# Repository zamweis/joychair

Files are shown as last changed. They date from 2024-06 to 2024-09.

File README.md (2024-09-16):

# Joychair - Interface for VR Navigation

Welcome to the Joychair Interface project! This project integrates the movements of an [Aeris Swopper chair](https://en.aeris.de/products/aeris-swopper-wollmischung-capture-gruen) into virtual reality (VR) environments, allowing users to navigate virtual worlds by shifting their weight on the chair. The idea is inspired by the concept of ChairIO, as described in the paper ["ChairIO - the Chair-Based Interface"](https://www.researchgate.net/publication/233819716_ChairIO--the_Chair-Based_Interface).

## Project Overview

The Joychair Interface project is developed at the iXperience Lab of the Faculty of Computer Science and Business Information Systems. The goal is to capture the movements of the Aeris Swopper chair and integrate them into a solution that can be used within VR environments, particularly in Unity.

The project was developed using the PlatformIO plugin for VSCode. The libraries used are also available for ArduinoIDE. The recommended version for wireless support is the ESP32 version; for wired, use the Arduino one.

## Project Components

### Hardware Parts
- M2.5 Machine Screws and Nuts
- 2000mAh Battery
- SPDT Slide Switch
- JST-PH (Male)
- JST-PH (Female)
- JST-PH extension cable (optional but helpful)
- Buzzer (active or passive)
- RGB LED (optional LED)
- MPU6050 (Inertial Measurement Unit)
- Compatible microcontroller (e.g., ESP32, Arduino)

### Hardware Setup

The project uses microcontroller boards with an IMU sensor attached to the chair. The IMU captures the chair's movements, which are then transmitted wirelessly or via wired connections.

- [Arduino Leonardo Setup](./arduino_leonardo)
- [ESP32 Setup](./esp32)
- [Feather 32u4 Bluefruit LE Setup](./feather32u4_bluefruit_le)

### Unity Integration

In Unity, the output is used to control the user's movement within the VR environment. By shifting their weight on the chair, users can navigate virtual worlds seamlessly.

## Setup Instructions

To set up the Joychair Interface project, follow these steps:

1. **Hardware Setup**: Attach the IMU sensor to the Aeris Swopper chair as per the instructions provided.
2. **Microcontroller Configuration**: Program the microcontroller board to read data from the IMU and transmit it wirelessly or via a wired connection.
3. **Unity Integration**: Import the output into Unity and configure the VR environment to respond to the chair's movements for navigation.
4. **Optional Casing**: For battery integration, follow a rechargeable battery tutorial. CAD for ESP32 is in progress.

## Features and Functionalities

The Joychair Interface provides several key functionalities:

### Initialization

- **MPU6050 Setup**: Initializes the MPU6050 IMU and ensures connectivity. Plays an initialization sound to confirm startup.

### Connection Management

- **Continuous Monitoring**: Checks the connection to the MPU6050 sensor and attempts to reconnect if the connection is lost, ensuring stable operation.

### Data Processing

- **Sensor Data Acquisition**: Reads data from the IMU, including yaw, pitch, and roll.
- **Axis Mapping**: Maps the processed sensor data to joystick axes (X, Y, Z, RX, RY, RZ) for VR navigation.

### Calibration and Direction Declaration

- **Sitting Detection**: Waits for the user to sit by monitoring acceleration in the Z-axis to exceed a threshold.
- **Forward Tilt Calibration**: Prompts the user to tilt forward to calibrate the forward direction. Plays a success sound upon completion.

### Joystick Output

- **Real-time Axis Mapping**: Continuously updates joystick inputs based on chair movement.
- **Deadzone Application**: Applies deadzones to joystick inputs to filter out noise and minor movements.

### Visual and Auditory Feedback

- **LED Indicators**: Uses RGB LED to provide visual status indicators, including connection status and error notifications.
- **Buzzer Sounds**: Emits sounds for different events such as initialization, errors, success, and setup completion.

### Battery Level Monitoring

- **Analog Reading**: Reads the battery level via Sparkfun Fuel Gauge

### Additional Functionalities

- **Jump Detection**: Detects rapid acceleration changes to emulate a "jump" button press.
- **Recalibration Button**: Allows recalibration of the forward direction by pressing a designated button on the microcontroller.
- **Reset Button**: Allows to reset the microcontroller.

## Axis Mapping and Joystick Calibration

When integrating the Joychair with a VR environment, it is essential to adjust the axis mappings to suit the target application's requirements. The joystick values, derived from the MPU6050 sensor readings, must be mapped within the appropriate intervals for your setup.

### Adjusting Axis Mapping

The mapping of the pitch, roll, and yaw values to joystick inputs is critical for achieving smooth and intuitive navigation. Depending on the VR application's sensitivity and control scheme, you may need to calibrate the mapping intervals.

1. **Define the Mapping Range:**
   - Determine the minimum and maximum tilt angles corresponding to the joystick's minimum and maximum values. This range should reflect the comfortable and natural tilting limits of the Aeris Swopper chair.

2. **Adjust the Intervals:**
   - Modify the code to map the sensor readings to the joystick values. Ensure the mapping intervals match the expected input range of your VR application. For instance, if your application expects joystick values from 0 to 32767, you need to map the sensor's tilt range to this interval.

3. **Minimum Tilt Threshold:**
   - Set a minimum tilt threshold to ensure that only intentional movements result in joystick input. This threshold helps filter out minor, unintentional shifts and maintains a stable VR navigation experience.

### Example Code Snippet for Axis Mapping

```cpp
// Define the minimum and maximum tilt angles (in degrees)
const float minTiltAngle = -10.0;
const float maxTiltAngle = 10.0;

// Define the joystick input range
const int joystickMinValue = 0;
const int joystickMaxValue = 32767;

// Function to map tilt to joystick value
int mapTiltToJoystick(float tiltAngle) {
    return map(tiltAngle, minTiltAngle, maxTiltAngle, joystickMinValue, joystickMaxValue);
}

// Example usage in the main loop
void loop() {
    // Get the tilt angles from the MPU6050
    float pitch = ...; // Get the pitch angle
    float roll = ...;  // Get the roll angle

    // Map the tilt angles to joystick values
    int joystickX = mapTiltToJoystick(pitch);
    int joystickY = mapTiltToJoystick(roll);

    // Apply the mapped values to the joystick
    bleGamepad.setAxes(joystickX, joystickY, ...);
}
```
## Additional Info ##

### Battery Level

LED Blink Red: Battery below 20%  
LED Blink Yellow: Battery over 20%   
LED Blink Green: Battery over 50%  

### Example

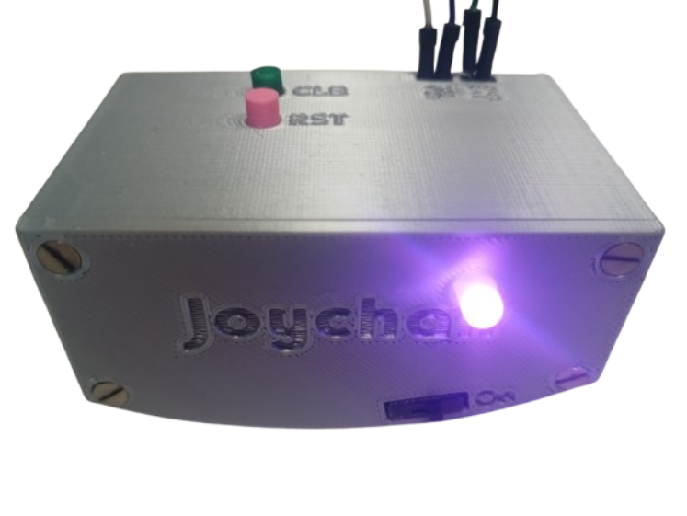
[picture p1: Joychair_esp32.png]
Joychair - ESP32


## Additional Resources

- [Aeris Swopper Product Page](https://en.aeris.de/products/aeris-swopper-wollmischung-capture-gruen): Learn more about the Aeris Swopper chair.
- [Arduino Joystick Tutorial](https://www.instructables.com/Create-a-Joystick-Using-the-Arduino-Joystick-Libra/): Useful guide for setting up the Arduino Leonardo as a joystick.
- [MPU6050 Wiring Guide](https://images.app.goo.gl/LdwjNLMtsEHgnhpH7): How to wire MPU6050
- [Buzzer Wiring Guide](https://images.app.goo.gl/mgFJdeP5EhSxzM8t5): How to wire a buzzer
- [RGB-LED Wiring Guide](https://images.app.goo.gl/b1UZzW2y5GSzTEi26): How to wire an RGB-LED
- [Rechargeable Battery Integration](https://learn.adafruit.com/3d-printed-case-for-adafruit-feather/assembly): How to wire a rechargeable battery  

## Contributors

- Sam Weiler (@zamweis)

## License

This project is licensed under the MIT License. See the [LICENSE](LICENSE) file for details.

---

Feel free to reach out to the project team for any questions or feedback. Happy navigating in VR with Joychair Interface! 🎮🪑🌐

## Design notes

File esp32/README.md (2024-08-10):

# Joychair Interface for VR Navigation - ESP32

Welcome to the Joychair Interface project for ESP32! This setup enables you to integrate the dynamic movements of an Aeris Swopper chair into virtual reality (VR) environments using a SparkFun ESP32 Thing board. The ESP32 communicates data wirelessly via Bluetooth, providing seamless interaction within VR applications.

## Project Overview

The Joychair Interface captures and translates the movements of the Aeris Swopper chair into VR environments, particularly in Unity. The setup uses an ESP32 microcontroller to read data from an Inertial Measurement Unit (IMU) and transmit it wirelessly. Additionally, the system includes a battery management solution, featuring a power switch and a fuel gauge for real-time battery monitoring.

## Hardware Setup

### Components
- **ESP32 (SparkFun ESP32 Thing)**
- **MPU6050 IMU (Inertial Measurement Unit)**
- **Buzzer**
- **RGB LED**
- **Battery with Power Switch**
- **MAX1704x Fuel Gauge**
- **Aeris Swopper Chair**

### Wiring
1. **MPU6050 IMU to ESP32:**
   - Connect via I2C (SDA to GPIO4, SCL to GPIO17).
   - Attach the IMU securely to the Aeris Swopper chair.
2. **Buzzer to ESP32:**
   - Connect the buzzer to a GPIO pin (e.g., GPIO6).
3. **RGB LED to ESP32:**
   - Connect the RGB LED to three GPIO pins (e.g., GPIO11 for red, GPIO10 for green, GPIO9 for blue).
4. **Battery Setup:**
   - Connect the battery to the power switch, and then connect the power switch to the MAX1704x fuel gauge.
   - Connect the fuel gauge to the ESP32 to monitor the battery level.
5. **Power and Ground Connections:**
   - Ensure all components share a common ground and are powered appropriately by the battery.

### Casing
The components should be housed securely to protect them from damage during use. You can 3D print the casing using the provided STL files.

### Spatial Light Transfer Files
You can find the STL files for the casing in the [case](./case) directory:
- [Case.stl](./case/case.STL)
- [Case_Lid.stl](./case/case_lid.STL)
- [Push_Button.stl](./case/push_button.STL)

## Software Setup

### Libraries
Ensure the following libraries are installed in your PlatformIO project:

```ini
lib_deps = 
    lemmingdev/ESP32-BLE-Gamepad@^0.5.5
    mbed-syundo0730/I2Cdev@0.0.0+sha.3aa973ebe3e5
    electroniccats/MPU6050@^1.3.1
    https://github.com/sparkfun/SparkFun_MAX1704x_Fuel_Gauge_Arduino_Library.git
```

## Functionality

### Battery Management
The setup includes a MAX1704x fuel gauge that monitors the battery level, providing real-time updates to the ESP32. This ensures the system can alert the user if the battery is running low, and manage power efficiently.

### LED Indicators
The RGB LED provides visual feedback on the system’s status:
- **Red Blinking:** An error has occurred.
- **Green Blinking:** Initialization is in progress.
- **Blue Blinking:** Bluetooth device is not connected.
- **Green Static:** Initialization completed successfully.
- **Pink Static:** System is operating normally.
- **Red/Yellow/Green (Static/Blinking):** Indicates battery level, where red indicates low battery, yellow indicates medium, and green indicates high.

### Code Overview
The provided code turns the ESP32 into a Bluetooth LE gamepad, which reads IMU data and transmits it over Bluetooth. It also manages power based on battery levels and provides visual and auditory feedback via the LED and buzzer.

## Usage Instructions
1. **Setup the hardware** according to the wiring instructions.
2. **Flash the code** to the ESP32 using PlatformIO.
3. **Power on the system** using the power switch connected to the battery.
4. **Monitor the LED indicators** to ensure everything is functioning correctly.
5. **Use the Joychair** to navigate in your VR environment, with movements of the Aeris Swopper chair translated directly into VR motion.

## Troubleshooting
- If the LED blinks red, check the connections and ensure all components are properly wired and powered.
- If the battery level is low, charge or replace the battery to ensure continuous operation.
- If the MPU6050 fails to initialize, verify the I2C connections and ensure the IMU is correctly attached to the ESP32.

## Conclusion
The Joychair Interface brings a new dimension to VR navigation, making interactions more immersive and intuitive. With proper setup and usage, this system can greatly enhance your VR experiences.

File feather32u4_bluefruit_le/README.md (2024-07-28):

# Joychair Interface for VR Navigation - Feather 32u4 Bluefruit LE

Welcome to the Joychair Interface project for Feather 32u4 Bluefruit LE! This setup allows you to integrate the movements of an Aeris Swopper chair into virtual reality (VR) environments using a Feather 32u4 Bluefruit LE board. Note: Currently, only wired transmission is supported as the Bluetooth function is not working properly.

## Project Overview

The Joychair Interface captures the movements of the Aeris Swopper chair and integrates them directly into VR environments, particularly in Unity. This setup uses the Feather 32u4 Bluefruit LE microcontroller to read data from an Inertial Measurement Unit (IMU) and transmit it via a wired connection.

## Hardware Setup

### Components
- **Feather 32u4 Bluefruit LE**
- **MPU6050 IMU**
- **Buzzer**
- **RGB LED**
- **Aeris Swopper Chair**

### Casing
3D-printed with Prusa MK2  
[Thingiverse](https://www.thingiverse.com/thing:2209964) file  
[Additional Tutorial](https://learn.adafruit.com/3d-printed-case-for-adafruit-feather/overview) for accu/battery integration  

### Wiring
1. Connect the MPU6050 IMU to the Feather 32u4 via I2C (SDA to SDA, SCL to SCL).
2. Connect the buzzer to a GPIO pin (e.g., GPIO6).
3. Connect the RGB LED to three GPIO pins (e.g., GPIO11 for red, GPIO10 for green, GPIO9 for blue).
4. Attach the MPU6050 IMU to the Aeris Swopper chair.

## Software Setup

### Libraries
Make sure you have the following libraries installed in your PlatformIO project:

```ini
lib_deps = 
    mbed-syundo0730/I2Cdev@0.0.0+sha.3aa973ebe3e5
    electroniccats/MPU6050@^1.3.1
    adafruit/Adafruit BluefruitLE nRF51@^1.0.0

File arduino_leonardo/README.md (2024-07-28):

# Joychair Interface for VR Navigation - Arduino Leonardo

Welcome to the Joychair Interface project for Arduino Leonardo! This setup allows you to integrate the movements of an Aeris Swopper chair into virtual reality (VR) environments using an Arduino Leonardo board and sensors.

## Project Overview

The Joychair Interface captures the movements of the Aeris Swopper chair and integrates them into a solution for VR environments, particularly in Unity. This setup uses the Arduino Leonardo microcontroller to read data from an Inertial Measurement Unit (IMU) and transmit it wirelessly/wired.

## Hardware Setup

### Components
- **Arduino Leonardo**
- **MPU6050 IMU**
- **Buzzer**
- **Aeris Swopper Chair**

### Casing
3D-printed with a prusa MK2  
[Thingiverse](https://www.thingiverse.com/thing:628929) file  

### Wiring
1. Connect the MPU6050 IMU to the Arduino Leonardo via I2C (SDA to A4, SCL to A5).
2. Connect the buzzer to pin 6 of the Arduino Leonardo.
3. Attach the MPU6050 IMU to the Aeris Swopper chair.

## Software Setup

### Libraries
Make sure you have the following libraries installed in your PlatformIO project:

```ini
lib_deps = 
    mheironimus/Joystick@^2.1.1
    mike-matera/ArduinoSTL@^1.3.3
    mbed-syundo0730/I2Cdev@0.0.0+sha.3aa973ebe3e5
    electroniccats/MPU6050@^1.3.1

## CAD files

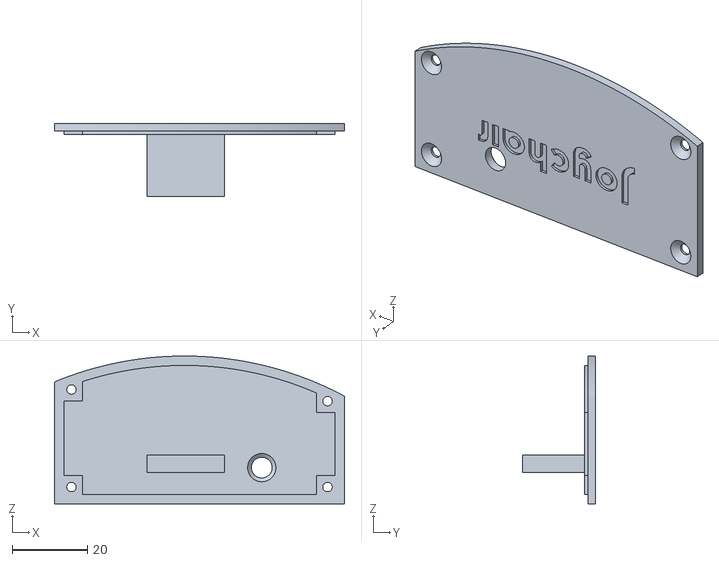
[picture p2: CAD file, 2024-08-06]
esp32/case/case_lid.STL
77.0 x 19.5 x 39.3

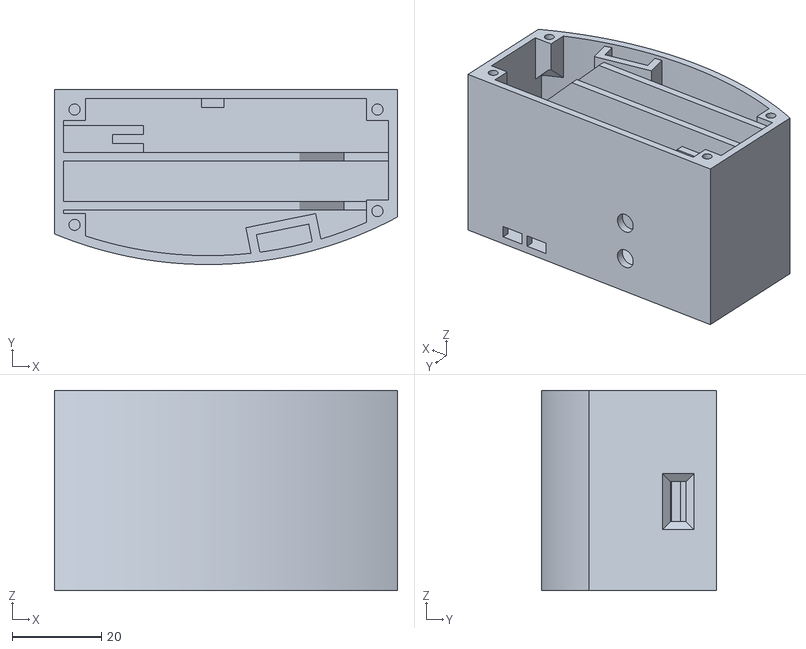
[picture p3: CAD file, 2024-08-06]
esp32/case/case.STL
77.0 x 39.3 x 45.0

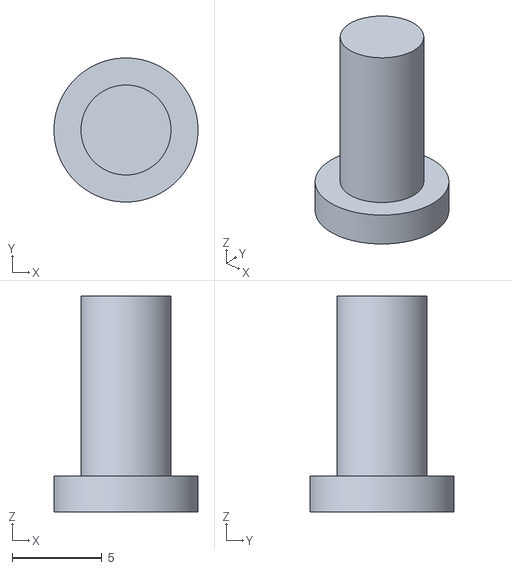
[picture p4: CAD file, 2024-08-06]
esp32/case/push_button.STL
8.00 x 8.00 x 12.0

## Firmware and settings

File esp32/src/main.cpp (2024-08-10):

/*
 * This example turns the ESP32 into a Bluetooth LE gamepad that presses buttons and moves axis
 *
 * At the moment we are using the default settings, but they can be canged using a BleGamepadConfig instance as parameter for the begin function.
 *
 * Possible buttons are:
 * BUTTON_1 through to BUTTON_16
 * (16 buttons by default. Library can be configured to use up to 128)
 *
 * Possible DPAD/HAT switch position values are:
 * DPAD_CENTERED, DPAD_UP, DPAD_UP_RIGHT, DPAD_RIGHT, DPAD_DOWN_RIGHT, DPAD_DOWN, DPAD_DOWN_LEFT, DPAD_LEFT, DPAD_UP_LEFT
 * (or HAT_CENTERED, HAT_UP etc)
 *
 * bleGamepad.setAxes sets all axes at once. There are a few:
 * (x axis, y axis, z axis, rx axis, ry axis, rz axis, slider 1, slider 2)
 *
 * Library can also be configured to support up to 5 simulation controls
 * (rudder, throttle, accelerator, brake, steering), but they are not enabled by default.
 *
 * Library can also be configured to support different function buttons
 * (start, select, menu, home, back, volume increase, volume decrease, volume mute)
 * start and select are enabled by default
 */

#include <BleGamepad.h>
#include <Wire.h>
#include "I2Cdev.h"
#include "MPU6050_6Axis_MotionApps20.h"
#include <SparkFun_MAX1704x_Fuel_Gauge_Arduino_Library.h>

// Define the number of buttons and hat switches
#define numOfButtons 1 // No physical buttons, no virtual buttons needed
#define numOfHatSwitches 0 // No hat switches

// Enable axes based on MPU6050 capabilities
#define enableX true
#define enableY true
#define enableZ true
#define enableRZ true
#define enableRX true
#define enableRY true
#define enableSlider1 false
#define enableSlider2 false
#define enableRudder false
#define enableThrottle false
#define enableAccelerator false
#define enableBrake false
#define enableSteering false

// Function and variable declarations
void blinkLED();
void recalibrate();
void playInitSound();
int getBatteryLevel();
void playErrorSound();
void playSuccessSound();
bool initializeMPU6050();
void printJoystickValues();
void playSetupCompleteSound();
void printRollPitchYawAccelZ();
void setLEDColor(String color);
int applyDeadzone(int value, int deadzone);
float calculateTilt(float pitch, float roll);
float calculateRelativeAngle(float accelX, float accelY, float accelZ);

// Define pin numbers for the RGB LED and button
int redPin = 26;
int greenPin = 25;
int bluePin = 27;
int buzzerPin = 13;
int bootButtonPin = 0;  // Boot button is typically connected to GPIO 0
long lastBlink = 0;  // will store last time LED was updated
long blinkInterval = 500;  // interval at which to blink (milliseconds)
bool isConnected = false;
bool blinkRed = false;
bool blinkGreen = false;
bool blinkYellow = false;


// Battery
int batteryPin = 36; // ADC1 channel 0 is GPIO36
float minBatteryVoltage = 3.0; // Minimum expected battery voltage (discharged LiPo)
float maxBatteryVoltage = 4.2; // Maximum expected battery voltage (fully charged LiPo)

uint16_t packetSize;
uint8_t fifoBuffer[64];

Quaternion q;
VectorFloat gravity;
float ypr[3];  // yaw, pitch, roll
float yaw;
float pitch;
float roll;
float accelX;
float accelY;
float accelZ;
float relativeAngle; // Angle of sensor rotation
float maxTiltAngle; // Maximal tilt angle of player

MPU6050 mpu;

SFE_MAX1704X lipo; // Defaults to the MAX17043

BleGamepad bleGamepad("Joychair", "iXperienceLab", 50);

int joystickX;
int joystickY;
int joystickZ;
int joystickRx;
int joystickRy;
int joystickRz;

float cosAngle;
float sinAngle; 

int jumpThreshold = 3000;

bool forwardDirectionDefined = false;
bool sittingCheckComplete = false;
bool mpuInitialized = false;
unsigned long lastTiltCheckTime = 0;
unsigned long lastJumpTime = 0; // Track the last jump time
const unsigned long jumpCooldown = 500; // 500ms cooldown between jumps
const unsigned long calibrationDuration = 5000; // Calibration duration in milliseconds
const float tiltMinimum = 5; // Tolerance for tilt check in radiants
const float sittingAccelZThreshold = 4000; // Threshold for detecting sitting
const float maxTiltTolerance = 45; // maximal estimated possible tilt 

void setup() {
  Serial.begin(115200);
  Wire.begin(4, 17);  
  playInitSound();

  digitalWrite(redPin, HIGH);
  digitalWrite(greenPin, LOW);
  digitalWrite(bluePin, HIGH);

  if (lipo.begin() == false) {
    Serial.println(F("MAX17043 not detected. Please check wiring. Freezing."));
    while (1)
      ;
  }
  
  lipo.quickStart();

  // initialize the digital pin as an output.
  pinMode(redPin, OUTPUT);
  pinMode(greenPin, OUTPUT);
  pinMode(bluePin, OUTPUT);

  // Initialize the battery pin as an input
  pinMode(batteryPin, INPUT);

  // Initialize the boot button pin as input with internal pull-up resistor
  pinMode(bootButtonPin, INPUT_PULLUP);

  Serial.println("Starting BLE work!");
  // Initialize BLE Gamepad
  BleGamepadConfiguration bleGamepadConfig;
  bleGamepadConfig.setControllerType(CONTROLLER_TYPE_GAMEPAD);
  bleGamepadConfig.setButtonCount(numOfButtons);
  bleGamepadConfig.setHatSwitchCount(numOfHatSwitches);
  bleGamepadConfig.setWhichAxes(enableX, enableY, enableZ, enableRX, enableRY, enableRZ, enableSlider1, enableSlider2);
  bleGamepadConfig.setWhichSimulationControls(enableRudder, enableThrottle, enableAccelerator, enableBrake, enableSteering);
  bleGamepadConfig.setModelNumber("1.0");
  bleGamepadConfig.setSoftwareRevision("Software Rev 1");
  bleGamepadConfig.setSerialNumber("1337");
  bleGamepadConfig.setFirmwareRevision("2.0");
  bleGamepadConfig.setHardwareRevision("4.0");

  bleGamepad.begin(&bleGamepadConfig);
  if (!initializeMPU6050()) {
    Serial.println("Failed to initialize MPU6050. Check connections and restart.");
    while (true) {
      delay(500);
      playErrorSound();
      delay(500);
    }
  }

  Serial.println("Waiting for player to sit down...");
  playInitSound();
}

void loop() {
  long currentMillis = millis();
  float soc = lipo.getSOC();
  // Set LED color based on battery level
  if (soc < 20.0) {
    setLEDColor("red");
  } else if (soc < 50.0) {
    setLEDColor("yellow");
  } else {
    setLEDColor("green");
  }  

  static unsigned long lastButtonPressTime = 0; 
  static bool lastButtonState = HIGH; 
  bool currentButtonState = digitalRead(bootButtonPin); 

  if (currentButtonState == LOW && lastButtonState == HIGH && currentMillis - lastButtonPressTime >= 1000) {
    recalibrate();  
    lastButtonPressTime = currentMillis; 
  }
  lastButtonState = currentButtonState; 

  if (!mpu.testConnection()) {
    Serial.println("MPU6050 connection lost. Trying to reconnect...");
    playErrorSound();
    unsigned long startAttemptTime = millis();
    while (!mpu.testConnection() && millis() - startAttemptTime < 10000) { 
      delay(500);
      Serial.print(".");
      if (!mpuInitialized) {
        initializeMPU6050();
      }
    }

    if (mpu.testConnection()) {
      Serial.println("MPU6050 reconnected.");
      playSuccessSound();
    } else {
      Serial.println("Failed to reconnect MPU6050.");
      playErrorSound();
      blinkLED();
      delay(5000); 
      return;
    }
  }

  if (mpu.dmpGetCurrentFIFOPacket(fifoBuffer)) {
    mpu.dmpGetQuaternion(&q, fifoBuffer);
    mpu.dmpGetGravity(&gravity, &q);
    mpu.dmpGetYawPitchRoll(ypr, &q, &gravity);

    accelZ = mpu.getAccelerationZ() - 16383;
    yaw = ypr[0] * 180 / M_PI;
    pitch = ypr[1] * 180 / M_PI;
    roll = ypr[2] * 180 / M_PI;

    if (!sittingCheckComplete) {
      if (accelZ > sittingAccelZThreshold) {
        playSuccessSound();
        sittingCheckComplete = true;
        Serial.println("Player detected.");
        Serial.println("Tilt forward and hold for a few seconds...");
        setLEDColor("green");
      }
      blinkLED();
      return;
    }

    if (!forwardDirectionDefined) {
      if (calculateTilt(pitch, roll) >= tiltMinimum) {
        if (lastTiltCheckTime == 0) {
          lastTiltCheckTime = millis(); 
          playInitSound();
        } else if (currentMillis - lastTiltCheckTime >= calibrationDuration) {
          relativeAngle = -calculateRelativeAngle(mpu.getAccelerationX(), mpu.getAccelerationY(), mpu.getAccelerationZ());
          Serial.print("Relative Angle: ");
          Serial.println(relativeAngle);

          forwardDirectionDefined = true;
          playSetupCompleteSound();
          Serial.println("Forward direction defined!");
          Serial.println("Setup Complete!");
        }
        if (maxTiltAngle < calculateTilt(pitch, roll) && calculateTilt(pitch, roll) <= maxTiltTolerance) {
          maxTiltAngle = calculateTilt(pitch, roll);
        }
      } else {
        if (lastTiltCheckTime != 0) { 
          playErrorSound();
        }
        lastTiltCheckTime = 0; 
      }
      blinkLED();
      return;
    }

    if (maxTiltAngle < calculateTilt(pitch, roll) && calculateTilt(pitch, roll) <= maxTiltTolerance) {
      maxTiltAngle = calculateTilt(pitch, roll);
    } 

    float cosAngle = -cos(relativeAngle);
    float sinAngle = -sin(relativeAngle);

    float newRoll = pitch * sinAngle + roll * cosAngle;
    float newPitch = pitch * cosAngle - roll * sinAngle;

    newRoll = constrain(newRoll, -maxTiltAngle, maxTiltAngle);
    newPitch = constrain(newPitch, -maxTiltAngle, maxTiltAngle);

    joystickX = map(newRoll, -maxTiltAngle, maxTiltAngle+1, 0, 32767);
    joystickY = map(newPitch, -maxTiltAngle, maxTiltAngle+1, 0, 32767);
    joystickZ = map(accelZ, -32767, 32767, 0, 32767);
    joystickRx = map(newRoll, -90, 90, 0, 32767);
    joystickRy = map(newPitch, -90, 90, 0, 32767);
    joystickRz = map(yaw, -180, 180, 0, 32767); 

    joystickX = applyDeadzone(joystickX, 5);
    joystickY = applyDeadzone(joystickY, 5);

    if (bleGamepad.isConnected()) {
      if (accelZ > jumpThreshold) {
        Serial.println("Jump detected!");
        bleGamepad.press(BUTTON_1);
      } else {
        bleGamepad.release(BUTTON_1);
      }
      bleGamepad.setAxes(joystickX, joystickY, joystickZ, joystickRz, joystickRx, joystickRy);
      bleGamepad.setBatteryLevel(soc);
      isConnected=true;
    } else {
      isConnected = false;
    }
  }
  blinkLED();
}

bool initializeMPU6050() {
  Serial.println("Initializing...");

  // Initialize MPU6050
  mpu.initialize();
  if (!mpu.testConnection()) {
    Serial.println("MPU6050 connection failed!");
    playErrorSound();
    mpuInitialized = false;
    return false;
  }

  // Initialize DMP
  uint8_t devStatus = mpu.dmpInitialize();
  if (devStatus == 0) {
    mpu.setDMPEnabled(true);
    packetSize = mpu.dmpGetFIFOPacketSize();
    Serial.println("DMP ready!");
    mpuInitialized = true;
  } else {
    Serial.print("DMP Initialization failed (code ");
    playErrorSound();
    Serial.print(devStatus);
    Serial.println(")");
    mpuInitialized = false;
    return false;
  }

  mpu.CalibrateAccel();
  mpu.CalibrateGyro();
  Serial.println("Calibration complete!");
  playSuccessSound();
  return true;
}

int applyDeadzone(int value, int deadzone) {
  // Calculate center of output range
  const int center = 511; // Center for range [0, 1023]
  int distance = value - center;

  // If the distance from the center is less than the deadzone, set output to center
  if (abs(distance) < deadzone) {
    return center;
  } else {
    // If outside the deadzone, adjust value linearly from the edge of the deadzone
    return (distance > 0) ? map(distance, deadzone, 511, center + deadzone, 1023) :
                            map(distance, -511, -deadzone, 0, center - deadzone);
  }
}

float calculateRelativeAngle(float accelX, float accelY, float accelZ) {
  // Normalize acceleration values
  float norm = sqrt(accelX * accelX + accelY * accelY + accelZ * accelZ);
  accelX /= norm;
  accelY /= norm;
  accelZ /= norm;

  // Calculate projection on XY-plane (ground projection)
  float proj_x = accelX;
  float proj_y = accelY;

  // Calculate angle in XY-plane relative to forward direction (positive y-axis)
  float angle = atan2(proj_y, proj_x);

  return angle;
}

float calculateTilt(float pitch, float roll){
  return max(abs(roll), abs(pitch));
}

void printRollPitchYawAccelZ() {
  Serial.print(F("roll: ")); Serial.print(roll);
  Serial.print(F(", pitch: ")); Serial.print(pitch);
  Serial.print(F(", yaw: ")); Serial.print(yaw);
  Serial.print(F(", accelZ: ")); Serial.println(accelZ);
}

void printJoystickValues(){
  Serial.print(F("joystickX: ")); Serial.print(joystickX);
  Serial.print(F(", joystickY: ")); Serial.print(joystickY);
  Serial.print(F(", joystickZ: ")); Serial.print(joystickZ);
  Serial.print(F(", joystickRx: ")); Serial.print(joystickRx);
  Serial.print(F(", joystickRy: ")); Serial.print(joystickRy);
  Serial.print(F(", joystickRz: ")); Serial.println(joystickRz);
}

void playInitSound() {
  setLEDColor("green");
  tone(buzzerPin, 1000);  // Play tone at 1000 Hz
  delay(150); // Continue for 150 ms
  noTone(buzzerPin); // Stop tone
  delay(150);
  tone(buzzerPin, 1000);
  delay(150);
  noTone(buzzerPin);
}

void playErrorSound() {
  setLEDColor("red");
  // The buzzer emits a distinct error sound by using a lower tone
  tone(buzzerPin, 500); // Play tone at 500 Hz
  delay(250); // Continue for 250 ms
  noTone(buzzerPin); // Stop tone
  delay(100); // Short pause
  tone(buzzerPin, 500); // Repeat tone at 500 Hz
  delay(250); // Continue for 250 ms
  noTone(buzzerPin); // Stop tone
}

void playSuccessSound() {
  setLEDColor("green");
  tone(buzzerPin, 1000); // Play tone at 1000 Hz
  delay(150); // Continue for 150 ms
  tone(buzzerPin, 1200); // Increase tone to 1200 Hz
  delay(150);
  tone(buzzerPin, 1400);
  delay(150);
  noTone(buzzerPin);
}

void playSetupCompleteSound() {
  setLEDColor("none");
  // Play a simple ascending tone to indicate completion
  tone(buzzerPin, 800); // Play tone at 800 Hz
  delay(150); // Continue for 150 ms
  tone(buzzerPin, 1000); // Increase tone to 1000 Hz
  delay(150); // Continue for 150 ms
  tone(buzzerPin, 1200); // Further increase tone to 1200 Hz
  delay(150); // Continue for 150 ms
  noTone(buzzerPin); // Stop tone

  // Add a short pause
  delay(150);

  // Play final high tone to signal readiness
  tone(buzzerPin, 1500); // Play higher tone at 1500 Hz
  delay(300); // Continue for 300 ms
  noTone(buzzerPin); // Stop tone
}

void blinkLED() {
  unsigned long currentMillis = millis();

  // Non-blocking LED blink code
  if (currentMillis - lastBlink >= blinkInterval) {
    // save the last time you blinked the LED
    lastBlink = currentMillis;

    if (isConnected) {
      // Toggle the LED states based on the control variables
      if (blinkRed) {
        digitalWrite(redPin, HIGH);
        digitalWrite(greenPin, LOW);
        digitalWrite(bluePin, LOW);
      } else if (blinkGreen) {
        digitalWrite(redPin, LOW);
        digitalWrite(greenPin, HIGH);
        digitalWrite(bluePin, LOW);
      } else if (blinkYellow) {
        digitalWrite(redPin, HIGH);
        digitalWrite(greenPin, HIGH);
        digitalWrite(bluePin, LOW);
      } else {
        // Default state Pink
        digitalWrite(redPin, HIGH);
        digitalWrite(greenPin, LOW);
        digitalWrite(bluePin, HIGH);
      }
    } else {
      if (blinkRed) {
        digitalWrite(redPin, !digitalRead(redPin));
        digitalWrite(greenPin, LOW);
        digitalWrite(bluePin, LOW);
      } else if (blinkGreen) {
        digitalWrite(redPin, LOW);
        digitalWrite(greenPin, !digitalRead(greenPin));
        digitalWrite(bluePin, LOW);
      } else if (blinkYellow) {
        digitalWrite(redPin, !digitalRead(redPin));
        digitalWrite(greenPin, !digitalRead(greenPin));
        digitalWrite(bluePin, LOW);
      } else {
        // Default state Pink
        digitalWrite(redPin, HIGH);
        digitalWrite(greenPin, LOW);
        digitalWrite(bluePin, HIGH);
      }
    }  
  }
}

void setLEDColor(String color) {
  // Set all blink flags to false initially
  blinkRed = false;
  blinkGreen = false;
  blinkYellow = false;

  // Statische Farben, wenn verbunden
  if (color == "red") {
    blinkRed = true;
  } else if (color == "green") {
    blinkGreen = true;
  } else if (color == "yellow") {
    blinkYellow = true;
  } else if (color == "none") {
    digitalWrite(redPin, HIGH);
    digitalWrite(greenPin, LOW);
    digitalWrite(bluePin, HIGH);
  }
}

// Reclibration for forward direction
void recalibrate() {
  Serial.println("CLB button pressed!");
  Serial.println("Waiting for new player");
  forwardDirectionDefined = false;
  sittingCheckComplete = false;
  maxTiltAngle = 0;
  setLEDColor("green");
  playInitSound();
}

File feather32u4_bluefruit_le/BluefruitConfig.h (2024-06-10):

// COMMON SETTINGS
// ----------------------------------------------------------------------------------------------
// These settings are used in both SW UART, HW UART and SPI mode
// ----------------------------------------------------------------------------------------------
#define BUFSIZE                        128   // Size of the read buffer for incoming data
#define VERBOSE_MODE                   false  // If set to 'true' enables debug output


// SOFTWARE UART SETTINGS
// ----------------------------------------------------------------------------------------------
// The following macros declare the pins that will be used for 'SW' serial.
// You should use this option if you are connecting the UART Friend to an UNO
// ----------------------------------------------------------------------------------------------
#define BLUEFRUIT_SWUART_RXD_PIN       9    // Required for software serial!
#define BLUEFRUIT_SWUART_TXD_PIN       10   // Required for software serial!
#define BLUEFRUIT_UART_CTS_PIN         11   // Required for software serial!
#define BLUEFRUIT_UART_RTS_PIN         -1   // Optional, set to -1 if unused


// HARDWARE UART SETTINGS
// ----------------------------------------------------------------------------------------------
// The following macros declare the HW serial port you are using. Uncomment
// this line if you are connecting the BLE to Leonardo/Micro or Flora
// ----------------------------------------------------------------------------------------------
#ifdef Serial1    // this makes it not complain on compilation if there's no Serial1
  #define BLUEFRUIT_HWSERIAL_NAME      Serial1
#endif


// SHARED UART SETTINGS
// ----------------------------------------------------------------------------------------------
// The following sets the optional Mode pin, its recommended but not required
// ----------------------------------------------------------------------------------------------
#define BLUEFRUIT_UART_MODE_PIN        12    // Set to -1 if unused


// HARDWARE SPI SETTINGS
// ----------------------------------------------------------------------------------------------
// The following macros declare the pins to use for HW SPI communication.
// SCK, MISO and MOSI should be connected to the HW SPI pins on the Uno, etc.
// This should be used with nRF51822 based Bluefruit LE modules that use SPI.
// ----------------------------------------------------------------------------------------------
#define BLUEFRUIT_SPI_CS               8
#define BLUEFRUIT_SPI_IRQ              7
#define BLUEFRUIT_SPI_RST              4    // Optional but recommended, set to -1 if unused

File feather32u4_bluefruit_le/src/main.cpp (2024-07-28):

/*********************************************************************
 This is an example for our nRF51822 based Bluefruit LE modules

 Pick one up today in the adafruit shop!

 Adafruit invests time and resources providing this open source code,
 please support Adafruit and open-source hardware by purchasing
 products from Adafruit!

 MIT license, check LICENSE for more information
 All text above, and the splash screen below must be included in
 any redistribution
*********************************************************************/

/*
  This example shows how to send HID (keyboard/mouse/etc) data via BLE
  Note that not all devices support BLE keyboard! BLE Keyboard != Bluetooth Keyboard
*/

#include <Arduino.h>
#include <SPI.h>
#if not defined(_VARIANT_ARDUINO_DUE_X_) && not defined(ARDUINO_ARCH_SAMD)
#include <SoftwareSerial.h>
#endif

#include "I2Cdev.h"
#include "MPU6050_6Axis_MotionApps20.h"
#include "Adafruit_BLE.h"
#include "Adafruit_BluefruitLE_SPI.h"
#include "Adafruit_BluefruitLE_UART.h"

#include "BluefruitConfig.h"

/*=========================================================================
    APPLICATION SETTINGS

    FACTORYRESET_ENABLE       Perform a factory reset when running this sketch
   
                              Enabling this will put your Bluefruit LE module
                              in a 'known good' state and clear any config
                              data set in previous sketches or projects, so
                              running this at least once is a good idea.
   
                              When deploying your project, however, you will
                              want to disable factory reset by setting this
                              value to 0.  If you are making changes to your
                              Bluefruit LE device via AT commands, and those
                              changes aren't persisting across resets, this
                              is the reason why.  Factory reset will erase
                              the non-volatile memory where config data is
                              stored, setting it back to factory default
                              values.
       
                              Some sketches that require you to bond to a
                              central device (HID mouse, keyboard, etc.)
                              won't work at all with this feature enabled
                              since the factory reset will clear all of the
                              bonding data stored on the chip, meaning the
                              central device won't be able to reconnect.
    MINIMUM_FIRMWARE_VERSION  Minimum firmware version to have some new features
    -----------------------------------------------------------------------*/
#define FACTORYRESET_ENABLE 1
/*=========================================================================*/


// Create the bluefruit object, either software serial...uncomment these lines
/*
SoftwareSerial bluefruitSS = SoftwareSerial(BLUEFRUIT_SWUART_TXD_PIN, BLUEFRUIT_SWUART_RXD_PIN);

Adafruit_BluefruitLE_UART ble(bluefruitSS, BLUEFRUIT_UART_MODE_PIN,
                      BLUEFRUIT_UART_CTS_PIN, BLUEFRUIT_UART_RTS_PIN);
*/

/* ...or hardware serial, which does not need the RTS/CTS pins. Uncomment this line */
// Adafruit_BluefruitLE_UART ble(BLUEFRUIT_HWSERIAL_NAME, BLUEFRUIT_UART_MODE_PIN);

/* ...hardware SPI, using SCK/MOSI/MISO hardware SPI pins and then user selected CS/IRQ/RST */
Adafruit_BluefruitLE_SPI ble(BLUEFRUIT_SPI_CS, BLUEFRUIT_SPI_IRQ, BLUEFRUIT_SPI_RST);

/* ...software SPI, using SCK/MOSI/MISO user-defined SPI pins and then user selected CS/IRQ/RST */
//Adafruit_BluefruitLE_SPI ble(BLUEFRUIT_SPI_SCK, BLUEFRUIT_SPI_MISO,
//                             BLUEFRUIT_SPI_MOSI, BLUEFRUIT_SPI_CS,
//                             BLUEFRUIT_SPI_IRQ, BLUEFRUIT_SPI_RST);


// LED 
int redPin = 11;
int greenPin = 10;
int bluePin = 9;
long previousMillis = 0;  // will store last time LED was updated
long interval = 250;      // interval at which to blink (milliseconds)

int16_t joystickX;
int16_t joystickY;
int16_t joystickZ;


// A small helper
void error(const __FlashStringHelper* err) {
  Serial.println(err);
  while (1)
    ;
}

void setup() {
  playInitSound();
  Serial.begin(115200);
  Wire.begin();
  Serial.println(F("Adafruit Bluefruit HID Gamepad"));
  Serial.println(F("---------------------------------------"));
  pinMode(buzzerPin, OUTPUT); // Set digital pin as output for the buzzer
  Joystick.begin(false);

   // Set the RGB LED pins as output
  pinMode(redPin, OUTPUT);
  pinMode(greenPin, OUTPUT);
  pinMode(bluePin, OUTPUT);
  pinMode(8, OUTPUT);  // Set digital pin 8 as an OUTPUT for buzzer
  playInitSound();
  delay(1000);

  if (!initializeMPU6050()) {
    Serial.println("Failed to initialize MPU6050. Check connections and restart.");
    while (true) {
      playErrorSound();
      delay(1000);
    }
  }

  if (!ble.begin(VERBOSE_MODE)) {
    error(F("Couldn't find Bluefruit, make sure it's in CoMmanD mode & check wiring?"));
  }
  Serial.println(F("OK!"));

  if (FACTORYRESET_ENABLE) {
    // Perform a factory reset to make sure everything is in a known state
    Serial.println(F("Performing a factory reset: "));
    ble.factoryReset();
  }

  // Disable command echo from Bluefruit
  ble.echo(false);

  Serial.println("Requesting Bluefruit info:");
  // Print Bluefruit information
  ble.info();

  // Enable HID Service if not enabled
  int32_t hid_en = 0;
  ble.sendCommandWithIntReply(F("AT+BLEHIDEN?"), &hid_en);
  if (!hid_en) {
    Serial.println(F("Enable HID: "));
    ble.sendCommandCheckOK(F("AT+BLEHIDEN=1"));
  }

  // Enable HID Service if not enabled
  int32_t gamepad_en = 0;
  ble.sendCommandWithIntReply(F("AT+BLEHIDGAMEPADEN?"), &gamepad_en);
  if (!gamepad_en) {
    Serial.println(F("Enable HID GamePad: "));
    ble.sendCommandCheckOK(F("AT+BLEHIDGAMEPADEN=1"));
  }

  if (!hid_en || !gamepad_en) {
    // Add or remove service requires a reset
    Serial.println(F("Performing a SW reset (service changes require a reset): "));
    !ble.reset();
  }

  Serial.println();
  Serial.println(F("Go to your phone's Bluetooth settings to pair your device"));
  Serial.println(F("then open an application that accepts gamepad input"));
  Serial.println();

  Serial.println("Waiting for player to sit down...");
  playInitSound();
}
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

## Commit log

2024-05-13 calibration and range mapping
2024-05-19 yaw working. best solution so far
2024-06-09 adafruit 32u4, rgb led
2024-07-25 z-axis rotation with relativeAngle
2024-07-28 disconnection of sensor proper handling
2024-07-28 esp32 code updates
2024-07-30 RGB LED, BLE working
2024-07-30 battery level, improved LED (battery level not working yet)
    [main.cpp]
2024-07-30 connection Status with led
2024-07-30 Update README.md - LED
2024-08-05 SCL SDA other pin mapping
2024-08-06 SLT upload for esp thing case
    [case.STL, case_lid.STL, push_button.STL]
2024-08-07 removed files
    [case.STL, case_lid.STL, push_button.STL]
2024-08-07 limit for maximal tilt tolerance
    [main.cpp]
2024-08-07 over limit bug x and y axis fix
    [main.cpp]
2024-08-10 Fuel Gauge, Battery Level
    Fuel Gauge implemented with led battery level feedback
